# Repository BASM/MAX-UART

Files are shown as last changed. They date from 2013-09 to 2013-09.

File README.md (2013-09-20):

MAX-UART
========

Stage: Stable

A board having convertor RX,TX and DTR,RTS pins.
The board was designed special for programming
Atmel AVR and NXP ARM microcontrollers.

Board used max3232 chip in SO16, used MOSFET transistors for
DTR, RTS level convert.

DTR and RTS used for Reset (ARM and AVR) and POI_3(for ARM).

Programs for programming is: 
* AVR -- Self  written from avr_boot project. 
  See https://github.com/BASM/avr_boot project.
* ARM -- lpc21isp. Project http://sourceforge.net/projects/lpc21isp/, https://github.com/Senseg/lpc21isp

CAD program is KiCAD.
Version 20130518 or newer.

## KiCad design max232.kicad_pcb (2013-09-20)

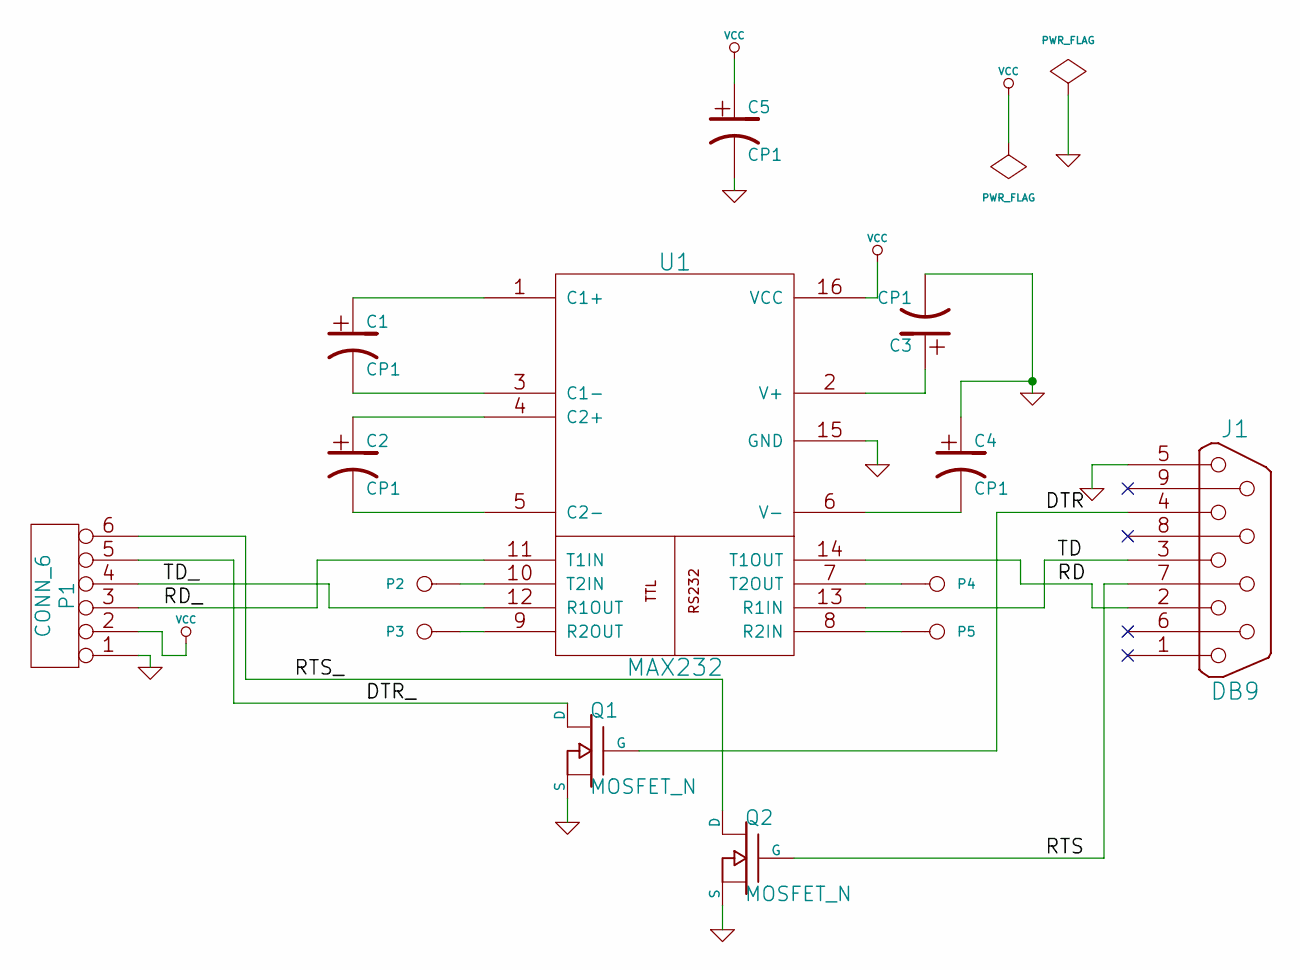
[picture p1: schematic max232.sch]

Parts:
C1, C2, C3, C4, C5: CP1
J1: DB9
P1: CONN_6
P2, P3, P4, P5: CONN_1
Q1, Q2: MOSFET_N
U1: MAX232

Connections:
/DTR: J1.4, Q1.G
/DTR_: P1.5, Q1.D
/RD: J1.2, U1.14 (T1OUT)
/RD_: P1.3, U1.11 (T1IN)
/RTS: J1.7, Q2.G
/RTS_: P1.6, Q2.D
/TD: J1.3, U1.13 (R1IN)
/TD_: P1.4, U1.12 (R1OUT)
GND: C3.2, C4.1, C5.2, J1.5, P1.1, Q1.S, Q2.S, U1.15 (GND)
unnamed: P5.1, U1.8 (R2IN)
unnamed: P2.1, U1.10 (T2IN)
unnamed: C3.1, U1.2 (V+)
unnamed: C4.2, U1.6 (V-)
unnamed: C2.1, U1.4 (C2+)
unnamed: C2.2, U1.5 (C2-)
unnamed: C1.2, U1.3 (C1-)
unnamed: C1.1, U1.1 (C1+)
unnamed: P3.1, U1.9 (R2OUT)
unnamed: P4.1, U1.7 (T2OUT)
VCC: C5.1, P1.2, U1.16 (VCC)

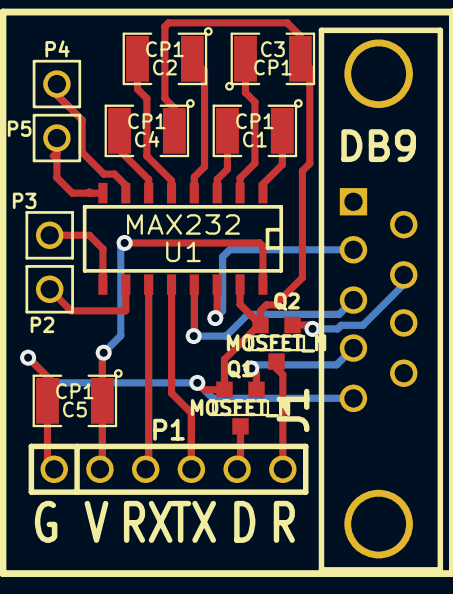
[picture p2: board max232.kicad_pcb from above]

Board: 2 copper layers, 14 parts (0 on the bottom side), 20 nets.

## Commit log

2012-05-17 First release
    [max232.sch]
2012-05-17 Added max232.brd, fixed uart.
    [max232.brd]
2013-08-16 Pre fix variant for iStudio
    [max232.brd, max232.sch]
2013-08-16 Version for iStudio.
    [max232.brd, max232.sch]
2013-09-05 Added max3232 variant include DTR RTS output.
    [max3232.sch]
2013-09-05 Fixed schemantick.
    [max232.brd, max232.sch]
2013-09-08 Fixed RX TX labels.
    [max232.brd, max232.sch]
2013-09-20 Added new version format of pcb (new KiCAD). Fixed name DTR<->RTS.
    [max232.kicad_pcb, max232.sch]
2013-09-20 Removed project max3232, max232 include max3232.
    [max3232.sch]
2013-09-20 Fix rename.sh script for new version of KiCAD
